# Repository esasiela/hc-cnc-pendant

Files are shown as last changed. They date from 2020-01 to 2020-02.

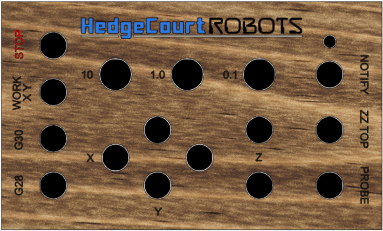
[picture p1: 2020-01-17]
production-2020/hc-cnc-pendant-2020-python/hc_device_emulator85.png

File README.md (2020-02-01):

# hc-cnc-pendant

This repository is for the software required to run an Arduino-based CNC Pendant and the Python software bridge that connects the pendant to a Gcode sender.

## HC CNC Pendant 2020

As of January 2020, the project completed a major overhaul.  The prototype is retired having completed pilot testing, and the production model is LIVE.

The full journey is documented in full photographic glory at [Hedge Court](https://www.hedgecourt.com/robots/cncPendant/).

The source tree in this repository is divided into the production and prototype trees, since they are total rewrites rather than incremental modifications.

The 2020 revision includes:

* Host pendant application rewritten in Python.  

* State information (jog size and units) stored in host application, opening the door to multiple client devices/emulators.

* Built-in pendant emulator, allowing the user a GUI to enter any commands that the hardware pendant device supports.

* Hardware client pendant in beautifully crafted wood enclosure, containing custom manufactured PCB holding an Arduino Nano controller.

* bCNC compatible. UGS testing underway.

## HC CNC Pendant v2 (2017 prototype)

The rest of this document is obsolete and pertains to the pendant v2 model, a prototype that launched in 2017.

* The sender is the control software that is connected to the CNC machine.  Senders are outside the scope of this repository.  The client/host that are part of this repostiory interface with the sender of your choice.  Currently tested with Universal Gcode Sender (UGS) and bCNC. Via modifications to the properties file, can support any web ui that takes a simple line of Gcode via a request parameter.

* The client is the physical pendant device powered by an Arduino, connected to the host computer via USB.

* The host is a Java application that runs on the host computer.  It listens to the client over USB, and feeds G-Code to the sender (UGS, bCNC) via the sender's pendant web UI.

* It is common that the host will run on the same computer as the sender, however this is not required.  URL references to localhost can be changed to the remote address of the sender.

## hc-cnc-pendant-client

This directory contains the Arduino sketch that runs on the pendant device.

## hc-cnc-pendant-host

This directory contains the host application Java source and resources plus Maven .pom project descriptor.

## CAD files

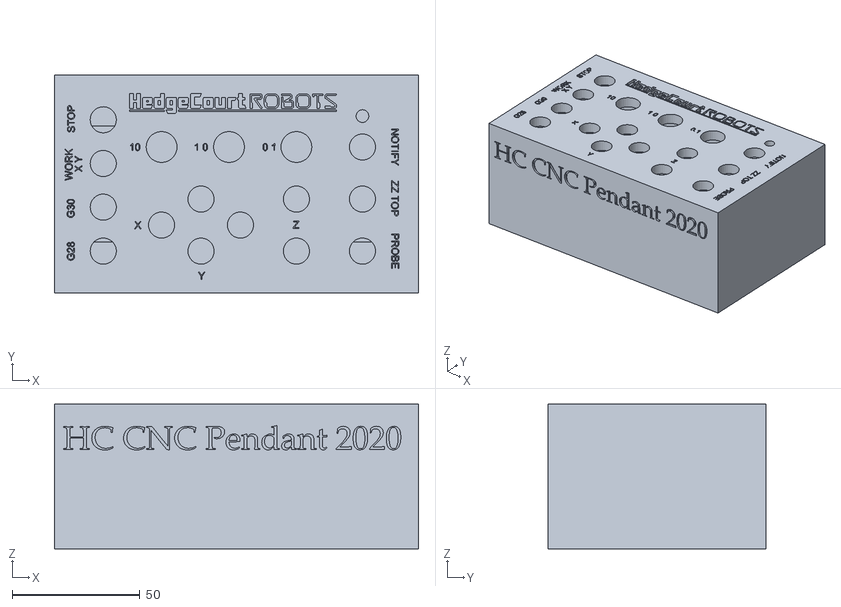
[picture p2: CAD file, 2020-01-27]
production-2020/hc-cnc-pendant-2020-cad/CNC_Pendant_2020.stl
142.7 x 85.3 x 56.8

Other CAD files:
production-2020/hc-cnc-pendant-2020-cad/CNC_Pendant_2020.f3d

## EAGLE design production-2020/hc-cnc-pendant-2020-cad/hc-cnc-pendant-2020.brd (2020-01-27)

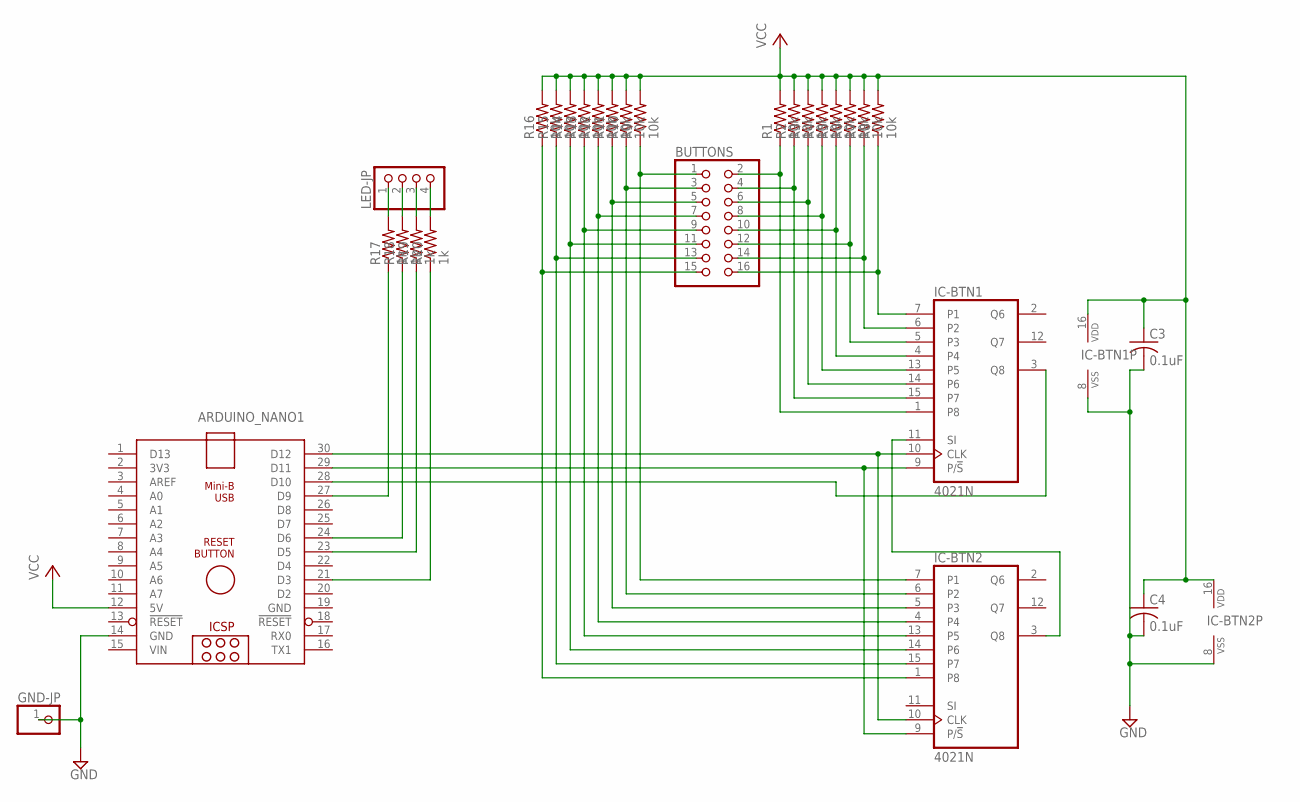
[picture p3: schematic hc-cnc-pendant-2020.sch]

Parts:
ARDUINO_NANO1: ARDUINO_NANO_HCARDUINO_NANO_NO_HOLE; ARDUINO_NANO_NO_HOLE
BUTTONS: PINHD-2X8; 2X08
C3, C4: 0.1uF; C025-030X050
GND-JP: PINHD-1X1; 1X01
IC-BTN1, IC-BTN2: 4021N; DIL16
LED-JP: PINHD-1X4; 1X04
R1, R2, R3, R4, R5, R6, R7, R8, R9, R10, R11, R12, R13, R14, R15, R16: 10k; 0309/12
R17, R18, R19, R20: 1k; 0309/12

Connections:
GND: ARDUINO_NANO1.14 (GND), ARDUINO_NANO1.19 (GND), C3.2, C4.2, GND-JP.1, IC-BTN1.8 (VSS), IC-BTN2.8 (VSS)
unnamed: ARDUINO_NANO1.30 (D12), IC-BTN1.10 (CLK), IC-BTN2.10 (CLK)
unnamed: ARDUINO_NANO1.29 (D11), IC-BTN1.9 (P/!S), IC-BTN2.9 (P/!S)
unnamed: BUTTONS.1, IC-BTN2.7 (P1), R9.1
unnamed: IC-BTN1.11 (SI), IC-BTN2.3 (Q8)
unnamed: ARDUINO_NANO1.28 (D10), IC-BTN1.3 (Q8)
unnamed: BUTTONS.3, IC-BTN2.6 (P2), R10.1
unnamed: BUTTONS.5, IC-BTN2.5 (P3), R11.1
unnamed: BUTTONS.7, IC-BTN2.4, R12.1
unnamed: BUTTONS.9, IC-BTN2.13 (P5), R13.1
unnamed: BUTTONS.11, IC-BTN2.14 (P6), R14.1
unnamed: BUTTONS.13, IC-BTN2.15 (P7), R15.1
unnamed: BUTTONS.15, IC-BTN2.1 (P8), R16.1
unnamed: BUTTONS.2, IC-BTN1.1 (P8), R1.1
unnamed: BUTTONS.4, IC-BTN1.15 (P7), R2.1
unnamed: BUTTONS.6, IC-BTN1.14 (P6), R3.1
unnamed: BUTTONS.8, IC-BTN1.13 (P5), R4.1
unnamed: BUTTONS.10, IC-BTN1.4, R5.1
unnamed: BUTTONS.12, IC-BTN1.5 (P3), R6.1
unnamed: BUTTONS.14, IC-BTN1.6 (P2), R7.1
unnamed: BUTTONS.16, IC-BTN1.7 (P1), R8.1
unnamed: LED-JP.1, R17.2
unnamed: LED-JP.2, R18.2
unnamed: LED-JP.3, R19.2
unnamed: LED-JP.4, R20.2
unnamed: ARDUINO_NANO1.21 (D3), R20.1
unnamed: ARDUINO_NANO1.23 (D5), R19.1
unnamed: ARDUINO_NANO1.24 (D6), R18.1
unnamed: ARDUINO_NANO1.27 (D9), R17.1
VCC: ARDUINO_NANO1.12 (5V), C3.1, C4.1, IC-BTN1.16 (VDD), IC-BTN2.16 (VDD), R1.2, R2.2, R3.2, R4.2, R5.2, R6.2, R7.2, R8.2, R9.2, R10.2, R11.2, R12.2, R13.2, R14.2, R15.2, R16.2
VIN: ARDUINO_NANO1.15 (VIN)

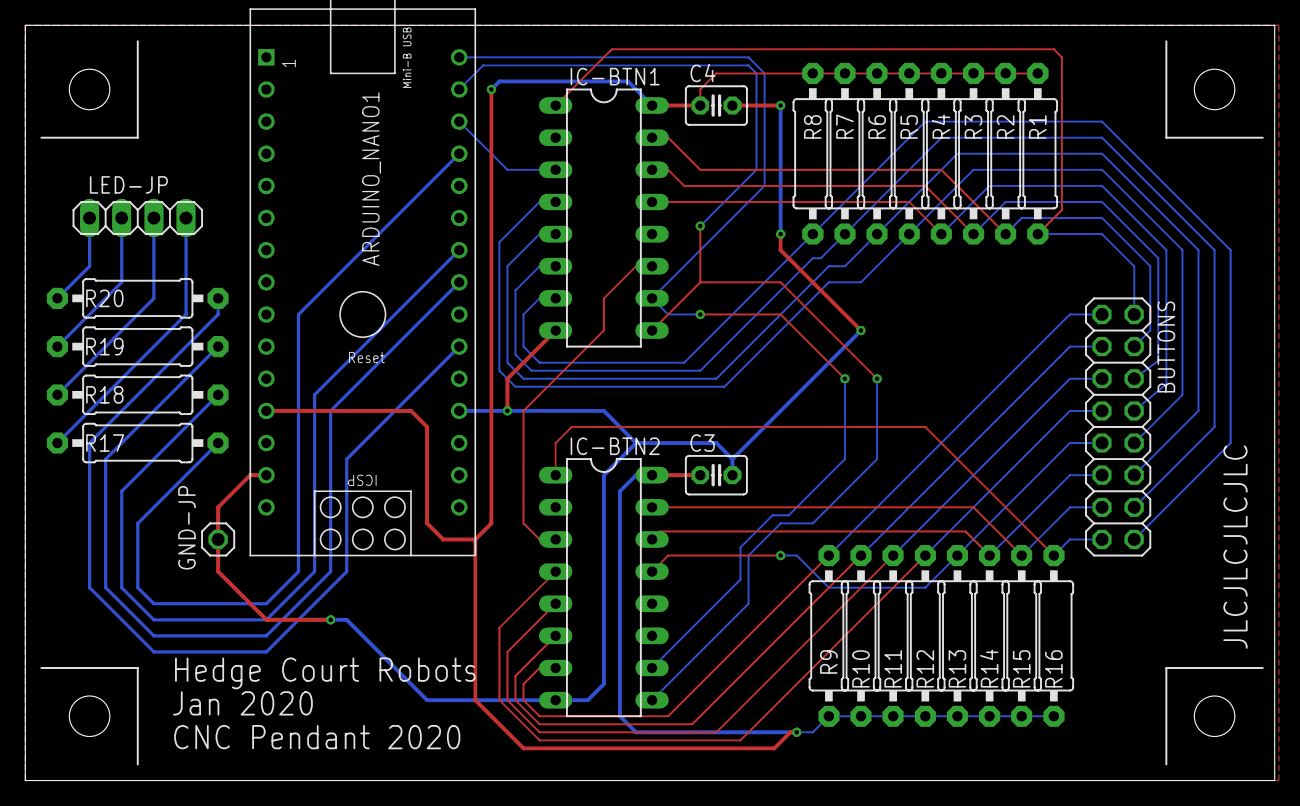
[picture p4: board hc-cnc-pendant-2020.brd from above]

Board: 2 copper layers, 98.7 x 59.7 mm, 28 parts (0 on the bottom side), 30 nets.

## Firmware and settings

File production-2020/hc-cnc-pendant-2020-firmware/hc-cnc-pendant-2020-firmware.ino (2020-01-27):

/*
   hc-cnc-pendant-firmware

   This is the Arduino Nano firmware for the Hedge Court CNC Pendant (v3, 2020)

   Pin Usage:

   3,5,6,9 - LED indicators (PWM output pins, only used as digital but future proofing)
   10,11,12 - Serial In register for 16 pushbuttons

*/

#include <EEPROM.h>
#include <HC_BouncyButton.h>

const int SERIAL_DEBUG = 0;


/***
   PIN definitions
*/

const int PIN_BTN_DATA = 10;
const int PIN_BTN_CLOCK = 12;
const int PIN_BTN_LATCH = 11;

const int PIN_LED_NOTIFY = 3;
const int PIN_LED_100 = 9;
const int PIN_LED_010 = 6;
const int PIN_LED_001 = 5;

// host will map JOG_SIZE_n to proper measurement size
const int JOG_SIZE_100 = 0;
const int JOG_SIZE_010 = 1;
const int JOG_SIZE_001 = 2;

// G-Code spec, 20=imperial, 21=metric
const int JOG_UNIT_INCH = 20;
const int JOG_UNIT_MM = 21;

// hc-pendant-2020 spec for data msg start (debugging strings DONT begin with 0x03)
const uint8_t MSG_START_BYTE = 0x03;

const uint8_t NOTIFY_IDLE = 0x01;
const uint8_t NOTIFY_ARMED = 0x02;
const uint8_t NOTIFY_FIRED = 0x03;

// the host app will send me the true notify state once I connect serial
uint8_t notifyState = NOTIFY_IDLE;

unsigned long lastNotifyBlinkMillis;
const int NOTIFY_BLINK_DELAY_MILLIS = 250;

// true on any change (press or release)
boolean isBtnRegisterChange = false;
// only true for press, not for release
boolean isBtnButtonPress = false;

uint16_t bouncingCurrentBtnRegister;
uint16_t bouncingPreviousBtnRegister;
uint16_t btnRegister;
uint16_t previousBtnRegister;

unsigned long lastDebounceTime;
const int DEBOUNCE_DELAY_MILLIS = 13;

// set the defaults to 10mm jog size
// hc-pendant-2020 does not offer any user interface to change from MM to inches, but we code it flexible anyways
byte jogSizeSelector = JOG_SIZE_100;
byte jogUnitSelector = JOG_UNIT_MM;


void updateUnitSelectorLED() {
  digitalWrite(PIN_LED_100, LOW);
  digitalWrite(PIN_LED_010, LOW);
  digitalWrite(PIN_LED_001, LOW);

  if (jogSizeSelector == JOG_SIZE_100) {
    digitalWrite(PIN_LED_100, HIGH);
  } else if (jogSizeSelector == JOG_SIZE_010) {
    digitalWrite(PIN_LED_010, HIGH);
  } else if (jogSizeSelector == JOG_SIZE_001) {
    digitalWrite(PIN_LED_001, HIGH);
  } else {
    Serial.println(F("invalid jog size selector is in the house, resetting to 10"));
    jogSizeSelector = JOG_SIZE_100;
    updateUnitSelectorLED();
  }
}

void setup() {

  Serial.begin(9600);
  delay(100);
  Serial.flush();
  Serial.println(F("HC CNC PENDANT 2020"));

  // button multiplexer
  pinMode(PIN_BTN_DATA, INPUT);
  pinMode(PIN_BTN_CLOCK, OUTPUT);
  pinMode(PIN_BTN_LATCH, OUTPUT);

  digitalWrite(PIN_BTN_LATCH, LOW);
  digitalWrite(PIN_BTN_CLOCK, HIGH);

  pinMode(PIN_LED_NOTIFY, OUTPUT);
  pinMode(PIN_LED_100, OUTPUT);
  pinMode(PIN_LED_010, OUTPUT);
  pinMode(PIN_LED_001, OUTPUT);

  digitalWrite(PIN_LED_NOTIFY, LOW);

  updateUnitSelectorLED();

}

void loop() {

  if (notifyState==NOTIFY_FIRED && (millis() - lastNotifyBlinkMillis) >= NOTIFY_BLINK_DELAY_MILLIS) {
    lastNotifyBlinkMillis = millis();
    digitalWrite(PIN_LED_NOTIFY, !digitalRead(PIN_LED_NOTIFY));
  }

  /***
     Check for client messages incoming on serial port.
     Pendant app will send Jog Size and Job Notify data.
     Client messages are 3 bytes:
     byte 0 - msg start, 0x03
     byte 1 - msg type - 0x01=jog_size, 0x02=notify
     byte 2 - data:
        jog_size - 13=10.0, 14=1.00, 15=0.10
        notify - IDLE=0x01, ARMED=0x02, FIRED=0x03
  */
  if (Serial.available() >= 3) {
    uint8_t start_byte = Serial.read();
    uint8_t msg_type  = Serial.read();
    uint8_t msg_data = Serial.read();

    if (start_byte == 0x03) {
      if (SERIAL_DEBUG) {
        Serial.println(F("client msg with valid start byte"));
      }

      if (msg_type == 0x01) {
        if (SERIAL_DEBUG) {
          Serial.println(F("client msg - jog size"));
        }

        if (msg_data == 13) {
          jogSizeSelector = JOG_SIZE_100;
        } else if (msg_data == 14) {
          jogSizeSelector = JOG_SIZE_010;
        } else if (msg_data == 15) {
          jogSizeSelector = JOG_SIZE_001;
        }
        updateUnitSelectorLED();

      } else if (msg_type == 0x02) {
        if (SERIAL_DEBUG) {
          Serial.println(F("client msg - notify"));
        }

        notifyState = msg_data;

        if (notifyState == NOTIFY_IDLE) {
          digitalWrite(PIN_LED_NOTIFY, LOW);
        } else if (notifyState == NOTIFY_ARMED) {
          digitalWrite(PIN_LED_NOTIFY, HIGH);
        } else if (notifyState == NOTIFY_FIRED) {
          // start blinking
          lastNotifyBlinkMillis = millis();
          // presumably we were in ARMED (unless I use my fake Fire! button for testing),
          // so LED was already on, so blinking is best to start by going low
          digitalWrite(PIN_LED_NOTIFY, LOW);
        }
      }
    }
  }

  /***
     read the multiplexed buttons
  */

  // latch HIGH and delay, allowing us to provide the LOW transition to begin reading
  digitalWrite(PIN_BTN_LATCH, HIGH);
  digitalWrite(PIN_BTN_CLOCK, HIGH);
  delayMicroseconds(20);
  // latch LOW tells the multiplexer to latch the button states so we can begin reading
  digitalWrite(PIN_BTN_LATCH, LOW);

  isBtnRegisterChange = false;
  bouncingCurrentBtnRegister = shiftIn(PIN_BTN_DATA, PIN_BTN_CLOCK, LSBFIRST) << 8;
  bouncingCurrentBtnRegister = bouncingCurrentBtnRegister | shiftIn(PIN_BTN_DATA, PIN_BTN_CLOCK, LSBFIRST);

  if (bouncingCurrentBtnRegister != bouncingPreviousBtnRegister) {
    // something is bouncing
    lastDebounceTime = millis();
  }

  isBtnRegisterChange = bouncingCurrentBtnRegister != btnRegister;

  if ((millis() - lastDebounceTime) > DEBOUNCE_DELAY_MILLIS && isBtnRegisterChange) {
    // bouncing is done and there is a state change, make it live
    previousBtnRegister = btnRegister;
    btnRegister = bouncingCurrentBtnRegister;

    // determine if it is a PRESS, we dont care about release
    for (byte bitIdx = 0; bitIdx < 16; bitIdx++) {
      boolean prevBit = previousBtnRegister & (1 << bitIdx);
      boolean curBit = btnRegister & (1 << bitIdx);

      // not equals means either press or relase....
      if (prevBit != curBit) {

        // we want only press eveents....curBit is LOW on a press event
        if (!curBit) {
          if (SERIAL_DEBUG) {
            Serial.print(F("Press Event - "));
            printBinary16(btnRegister);
            Serial.println("");
            Serial.flush();
            delay(10);
          }

          /* 
           * buttons 13-15 are the unit selectors. 
           * handle the press same as the others.
           *   * send button event to host
           *   * host determines new unit size
           *   * host sends unit size information back to me in a client msg
           *   * i update my led in response to the client msg
           * this allows sync between pendant hardware and emulator, since host manages state
           */

          // byte 0 : MSG_START_BYTE
          // byte 1 : button number (bitIdx)
          // byte 2 : mm/inch (Pendant 2020 always sends 21, royale with cheese)
          // OBSOLETE - jog size is maintained in Pendant application in HC Pendant 2020 version
          // byte 3 : jog size (0=10.0, 1=01.0, 2=0.10)

          Serial.flush();
          Serial.write(MSG_START_BYTE);
          Serial.write(bitIdx);
          Serial.write(jogUnitSelector);
          //Serial.write(jogSizeSelector);
          Serial.println("");
        }
      }
    }
  }

  // update the "previous" value for the next iteration
  bouncingPreviousBtnRegister = bouncingCurrentBtnRegister;
}

void printBinary16(uint16_t x) {
  int idx;
  for (idx = 16; idx > 0; idx--) {
    if (idx == 8) {
      Serial.print(" ");
    }
    if ((x >> (idx - 1)) & 1) {
      Serial.print("1");
    } else {
      Serial.print("0");
    }
  }
}

void printBinaryByte(byte b) {
  int x;
  for (x = 8; x > 0; x--) {
    if ((b >> (x - 1)) & 1) {
      Serial.print("1");
    } else {
      Serial.print("0");
    }
  }
}

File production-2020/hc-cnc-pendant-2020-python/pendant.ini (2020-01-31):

[DEFAULT]

# email config gets programmatically added into this by __main__ application.
# format of pendant-email.ini is as follows (and should be kept out of this
# file, and out of the source tree entirely)
#[EMAIL]
#email_server=SERVER
#email_port=PORT
#email_from=FROM_ADDR
#email_password=FROM_PASSWORD
#email_to=TO_ADDR


# string the device sends over serial to indicate it is done booting
serial_device_start_msg=HC CNC PENDANT 2020

##### Probe configuration
# _mm is the thickness of plate or diameter of tool (in mm, naturally)

probe_plate_1_name=HC Angle
probe_plate_1_mm=1.5748
probe_plate_2_name=Fake Placeholder
probe_plate_2_mm=5.5555

probe_tool_1_name=Quarter Inch
probe_tool_1_mm=6.35
probe_tool_2_name=Half Inch
probe_tool_2_mm=12.7
probe_tool_3_name=Eighth Inch
probe_tool_3_mm=3.175

# probe gcode:
#  [AXIS] - X, Y, Z
#  [DIR_FW] - Z probes negative so val is '-', XY probe positive so val is '' blank
#  [DIR_BK] - opposite of DIR_FW, Z='', XY='-'
#  [OFFSET_MM] - Z=plate_mm, XY=plate_mm+(tool_diameter/2)

# M5; G17; G20; G91 G38.2 z-.5 F2; G0 z.03; G38.2 z-.1 F1; G10 L20 P0 z.062; G0 z.1; G90
#probe_gcode_z=M5; G17; G21; G91 G38.2 z-12.7 F2; G0 z0.762; G38.2 z-1.000 F1; G10 L20 P0 z[OFFSET_MM]; G0 z10.0; G90
#              M5; G17; G21; G91 G38.2 Z-12.7 F2; G0 Z0.762; G38.2 Z-1.000 F1; G10 L20 P0 Z1.5748; G0 Z10.0; G90
#              M5; G17; G21; G91 G38.2 X12.7 F2; G0 X-0.762; G38.2 X1.000 F1; G10 L20 P0 X-4.7498; G0 X-10.0; G90
#probe_gcode_xy=M5; G17; G21; G91 G38.2 [AXIS]12.7 F2; G0 [AXIS]-0.762; G38.2 [AXIS]1.000 F1; G10 L20 P0 [AXIS][OFFSET_MM]; G0 [AXIS]-10.0; G90
probe_gcode=M5; G17; G21; G91 G38.2 [AXIS][DIR_FW]12.7 F20.0; G0 [AXIS][DIR_BK]0.50; G38.2 [AXIS][DIR_FW]0.60 F5.0; G10 L20 P0 [AXIS][DIR_BK][OFFSET_MM]; G0 [AXIS][DIR_BK]10.0; G90


##### Device Button Configuration

# processing looks in the following order:
#   if "btn_N_stop" exists, this is _the_ STOP button
#   if "btn_N_notify" exists, this is _the_ NOTIFY button
#   if "btn_N_probe" exists, this is _the_ PROBE button
#   if "btn_N_size" exists, this is a JOG_SIZE button
#   if "btn_N_gcode" exists, this is a GCODE button
#   if "btn_N_axis" exists, this is a JOG button

btn_13_size=10.0
btn_14_size=1.00
btn_15_size=0.10

btn_12_gcode=G53 G0 Z0
btn_11_gcode=G90 G0 X0 Y0
btn_10_gcode=G53 G0 Z0; G30
btn_9_gcode=G53 G0 Z0; G28

# technically, PROBE for Z axis only can be implemented as straight gcode
btn_8_probe=True
# btn_8_gcode=M5; G17; G20; G91 G38.2 z-.5 F2; G0 z.03; G38.2 z-.1 F1; G10 L20 P0 z.062; G0 z.1; G90

btn_7_notify=True
btn_6_stop=STOP

# buttons 0-5 are reserved for the six +/- XYZ buttons
btn_5_axis=Z
btn_5_dir=
btn_4_axis=Z
btn_4_dir=-

btn_3_axis=Y
btn_3_dir=
btn_2_axis=Y
btn_2_dir=-

btn_1_axis=X
btn_1_dir=
btn_0_axis=X
btn_0_dir=-

# JOG_UNIT comes directly from the message
# JOG_AXIS/JOG_DIR come from the btn assignments above
# JOG_SIZE maps from the message using the assignment below
jog_gcode_pattern=G[JOG_UNIT] G91 G0 [JOG_AXIS][JOG_DIR][JOG_SIZE]

# jog_size is replaced by btn_N_size up above
#jog_size_13=10.0
#jog_size_14=1.00
#jog_size_15=0.10


######## config for specific gcode senders

# the char specified in gcode.separator will be replaced with the sender-specific separator.
# essentially, in this config file, we use semicolon to separate gcode instructions on a single line.
# bCNC uses \n to separate them, so we replace.  UGS can accept the semicolon directly
gcode_separator=;
cmd_separator=;

# sender_list is a comma-separated list of sender names.  Case insensitive so put 'bCNC', and we'll look
# for config using toLower 'bcnc' 'ugs'
gcode_sender_list=bCNC,UGS

# this is the default that will be enabled at pendant start
gcode_sender_default=bcnc

bcnc_gcode_url=http://localhost:8080/send
bcnc_gcode_paramName=gcode
bcnc_gcode_separator=\n
bcnc_gcode_outputResponse=true

bcnc_cmd_url=http://localhost:8080/send
bcnc_cmd_paramName=cmd
bcnc_cmd_separator=\n
bcnc_cmd_outputResponse=true

# automatically visit the index page every N seconds (0 means never)
# I only plan on implementing this if i roll out UGS compatibility, really only useful for the very
# first webUI hit to UGS after UGS starts up.  bCNC doesn't have similar need.
bcnc_index_visit_seconds=0
bcnc_index_url=http://localhost:8080/getSystemState
bcnc_index_outputResponse=false

# strings bcnc writes to stdout when a job starts/stops
bcnc_stdin_start=Controller state changed to: Run (Running: True)
bcnc_stdin_stop=Controller state changed to: Idle (Running: False)

####### Config for basic application system properties

# in development, left monitor is #1, right is #2
window_position=True
window_monitor=1
window_x=750
window_y=250

gui_frame_console_clear=Clear
gui_frame_log_title=Log Console
gui_frame_gcode_title=G-Code History
gui_frame_stdin_title=STDIN

gui_frame_gcode_clear=Clear

gui_frame_probe_title=Probe
gui_frame_notify_title=Job Notify
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

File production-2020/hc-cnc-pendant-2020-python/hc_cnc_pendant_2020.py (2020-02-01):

from threading import Thread, Condition
import requests
from queue import Queue
# from enum import Enum, auto
import serial.tools.list_ports
import serial
import sys
from datetime import datetime, timedelta, date, time
import configparser

from PyQt5.QtCore import QObject, pyqtSignal, Qt
from PyQt5.QtWidgets import QApplication, QWidget, QFrame, QLabel, QVBoxLayout, QHBoxLayout, QPushButton, QComboBox, QHBoxLayout, \
    QRadioButton, QGridLayout,  QCheckBox, QDesktopWidget, QMainWindow, QTabWidget

from hc_observable import ThreadedObserver
from hc_device_emulator import PendantEmulator
from hc_cnc_console import ConsoleFrame, StdinFrame
from hc_cnc_notify import NotifyFrame, NotifyManager
from hc_cnc_constants import LogTypes, JobStates


def rgb_from_config(color_str="0,0,0"):
    return [int(c) for c in color_str.split(',')]


class SerialConnectionWidget(QFrame):
    """
    Widget to let user see available serial comm ports and manage the connection.
    """
    def __init__(self, parent=None, pendant=None):
        QFrame.__init__(self, parent)

        # tell the pendant object that I want to know about serial connection changes
        pendant.observe_serial_connection(self)

        self.setFrameStyle(QFrame.StyledPanel)

        self.pendant = pendant
        self.port_combobox = None
        self.connect_button = None

        layout = QVBoxLayout()
        layout.addWidget(QLabel(self.pendant.config["gui_frame_serial_title"]))

        port_frame = QWidget()
        port_layout = QHBoxLayout()

        self.port_combobox = QComboBox()
        self.click_refresh()
        port_layout.addWidget(self.port_combobox)

        port_refresh_button = QPushButton(self.pendant.config["gui_frame_serial_refresh"])
        port_refresh_button.clicked.connect(self.click_refresh)
        port_layout.addWidget(port_refresh_button)

        port_layout.setContentsMargins(0, 0, 0, 0)
        port_frame.setLayout(port_layout)

        # connect_frame = QWidget()
        # connect_layout = QHBoxLayout()
        self.connect_button = QPushButton(self.pendant.config["gui_frame_serial_connect"])
        self.connect_button.clicked.connect(self.click_connect)
        # connect_layout.addWidget(self.connect_button)
        # connect_layout.setContentsMargins(0, 0, 0, 0)
        # connect_frame.setLayout(connect_layout)

        layout.addWidget(port_frame)
        # layout.addWidget(connect_frame)
        layout.addWidget(self.connect_button)
        self.setLayout(layout)

    def serial_connection_event(self, debug=False):
        if debug:
            self.pendant.log("serial widget - handling serial connection event")

        if self.pendant.is_serial_connected():
            self.connect_button.setText(self.pendant.config["gui_frame_serial_disconnect"])
        else:
            self.connect_button.setText(self.pendant.config["gui_frame_serial_connect"])

    def click_refresh(self):
        if self.port_combobox is not None:
            self.port_combobox.clear()
            for p in serial.tools.list_ports.comports():
                self.port_combobox.addItem(str(p))

    def click_connect(self):
        # self.pendant.log("clicked connect [" + self.port_combobox.currentText() + "]")
        if self.pendant.is_serial_connected():
            self.pendant.serial_disconnect()
            # self.connect_button.setText("Connect")
        else:
            self.pendant.serial_connect(self.port_combobox.currentText().split(" ")[0])
            # if self.pendant.is_serial_connected():
            #    self.connect_button.setText("Disconnect")


class ProbeComboBox(QComboBox):
    def __init__(self, parent=None, pendant=None, key_prefix=None):
        QComboBox.__init__(self, parent)
        self.pendant = pendant
        self.key_prefix = key_prefix
        self.load_items()

    def load_items(self):
        for k, v in self.pendant.config.items():
            if k.startswith(self.key_prefix) and k.endswith("_name"):
                # we have a name key.  also need the matching mm key
                try:
                    name = v
                    mm = self.pendant.config.get(k.replace("_name", "_mm"))
                    if mm is None:
                        raise KeyError()

                    self.addItem(name + " (" + str(mm) + " mm)", mm)
                except KeyError:
                    self.pendant.log("config error for " + self.key_prefix + ", skipping")


class ProbeFrame(QFrame):
    """
    Widget to manage the axis probe macros.  Spends most of its life in Z axis, with the occasional
    XY when I use a custom fixture rather than the standard bumpstop zero'ed on G28.
    """
    def __init__(self, parent=None, pendant=None):
        QFrame.__init__(self, parent)
        self.pendant = pendant

        self.setFrameStyle(QFrame.StyledPanel)
        layout = QVBoxLayout()
        layout.addWidget(QLabel(self.pendant.config["gui_frame_probe_title"]))

        plate_frame = QFrame()
        plate_layout = QHBoxLayout()
        plate_layout.setContentsMargins(0, 0, 0, 0)
        plate_layout.addWidget(QLabel("Touch plate:"))
        self.plate_combobox = ProbeComboBox(pendant=self.pendant, key_prefix="probe_plate")
        self.plate_combobox.currentIndexChanged.connect(self.change_plate_selection)
        self.change_plate_selection(1)
        plate_layout.addWidget(self.plate_combobox)
        plate_layout.addStretch()
        plate_frame.setLayout(plate_layout)

        layout.addWidget(plate_frame)

        grid_frame = QWidget()
        grid_layout = QGridLayout()
        grid_layout.setContentsMargins(0, 0, 0, 0)

        rb = QRadioButton("Z")
        rb.axis = "Z"
        rb.setChecked(True)
        rb.toggled.connect(self.change_axis_selection)
        grid_layout.addWidget(rb, 0, 0)

        rb = QRadioButton("X")
        rb.axis = "X"
        rb.toggled.connect(self.change_axis_selection)
        grid_layout.addWidget(rb, 0, 1)

        rb = QRadioButton("Y")
        rb.axis = "Y"
        rb.toggled.connect(self.change_axis_selection)
        grid_layout.addWidget(rb, 0, 2)

        self.tool_combobox = ProbeComboBox(pendant=self.pendant, key_prefix="probe_tool")
        self.tool_combobox.currentIndexChanged.connect(self.change_tool_selection)
        self.change_tool_selection(1)

        grid_layout.addWidget(QLabel("Select Tool for X/Y:"), 1, 1, 1, 2)
        grid_layout.addWidget(self.tool_combobox, 2, 1, 1, 2)

        grid_frame.setLayout(grid_layout)

        layout.addWidget(grid_frame)

        self.setLayout(layout)

    def change_axis_selection(self):
        rb: QRadioButton = self.sender()
        if rb.isChecked():
            # if debug:
            #    self.pendant.log("probe axis selection changed: " + rb.axis)
            self.pendant.probe_axis = rb.axis
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
